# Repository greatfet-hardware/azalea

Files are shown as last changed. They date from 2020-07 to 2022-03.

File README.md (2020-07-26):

# Azalea

Hardware licensed under the BSD 3 clause license
Documentation licensed under the BSD 3 clause license

This repository contains the KiCad design for Azalea, also known as GreatFET One.  The design requires:

https://github.com/greatscottgadgets/gsg-kicad-lib

If you are using git, the preferred way to install gsg-kicad-lib is to use the submodule:

```
git submodule init && git submodule update
```

## Overview

Also known as GreatFET One, Azalea is the main board of the GreatFET project.

Azalea is a peripheral interface tool.  By adding expansion boards called "neighbors", you can turn Azalea into a USB peripheral that does almost anything.

Features:
* LPC4330 microcontroller (U1)
* Hi-Speed USB port (USB0) for connection to a host computer
* Expansion interface (J1 and J2) of 80 pins (2 female headers with 2 rows of 20 pins)
* Bonus row of 20 male pins (J7)
* 4 indicator LEDs
* 2 buttons, primarily for development (DFU and RESET, just like HackRF One)
* Full Speed USB port (USB1) for connection to a target (for [Facedancer](https://github.com/usb-tools/Facedancer))
* Power switching for use of USB1 as either host or device
* 3.3 V regulator that can supply some power to neighbors
* 2 MB flash memory
* Unpopulated Cortex Debug Header (J5) for JTAG or SWD

Except where noted below, all pins on expansion ports use 3.3 V I/O voltage.

## J1 (NEIGHBOR1) Pinout

Pin|Symbol|Special Function|Notes    |U1 Pin|GPIO |U0 |U1 |U2  |EMC        |SGPIO|ENET      |CAN1|SSP0|SSP1|I2S0           |I2S1  |USB0     |USB1     |SD   |MISC   |PWM  |TIMER  |SCT     
---|------|----------------|---------|------|-----|---|---|----|-----------|-----|----------|----|----|----|---------------|------|---------|---------|-----|-------|-----|-------|--------
1  |GND   |                |         |      |     |   |   |    |           |     |          |    |    |    |               |      |         |         |     |       |     |       |        
2  |VCC   |                |3.3 V    |      |     |   |   |    |           |     |          |    |    |    |               |      |         |         |     |       |     |       |        
3  |P4_9  |                |         |33    |5[13]|   |   |    |           |14   |          |RD  |    |    |               |      |         |         |     |       |     |       |CTIN_6  
4  |P0_0  |                |         |32    |0[0] |   |   |    |           |0    |RXD1      |    |    |CIPO|TX_WS          |TX_WS |         |         |     |       |     |       |        
5  |P4_10 |                |         |35    |5[14]|   |   |    |           |15   |          |    |    |    |               |      |         |         |     |       |     |       |CTIN_2  
6  |P0_1  |                |         |34    |0[1] |   |   |    |           |1    |TX_EN     |    |    |COPI|               |TX_SDA|         |         |     |       |     |       |        
7  |P1_0  |                |         |38    |0[4] |   |   |    |A5         |7    |          |    |CS  |    |               |      |         |         |     |       |     |       |CTIN_3  
8  |P5_0  |                |         |37    |2[9] |   |DSR|    |D12        |     |          |    |    |    |               |      |         |         |     |       |MCOB2|T1_CAP0|        
9  |P5_1  |                |         |39    |2[10]|   |DTR|    |D13        |     |          |    |    |    |               |      |         |         |     |       |MCI2 |T1_CAP1|        
10 |P1_1  |boot mode       |pull-up  |42    |0[8] |   |   |    |A6         |8    |          |    |CIPO|    |               |      |         |         |     |       |     |       |CTOUT_7 
11 |CLK0  |                |         |45    |     |   |   |    |CLK0, CLK01|     |REF_CLK   |    |    |SCK |               |      |         |         |CLK  |CLKOUT |     |       |        
12 |P1_2  |boot mode       |pull-down|43    |0[9] |   |   |    |A7         |9    |          |    |COPI|    |               |      |         |         |     |       |     |       |CTOUT_6 
13 |P1_5  |                |         |48    |1[8] |   |   |    |CS0#       |15   |          |    |    |CS  |               |      |PWR_FAULT|         |POW  |       |     |       |CTOUT_10
14 |P5_2  |                |         |46    |2[11]|   |RTS|    |D14        |     |          |    |    |    |               |      |         |         |     |       |MCI1 |T1_CAP2|        
15 |P1_7  |                |         |50    |1[0] |   |DSR|    |D0         |     |          |    |    |    |               |      |PPWR     |         |     |       |     |       |CTIN_1  
16 |P1_6  |                |         |49    |1[9] |   |   |    |WE#        |14   |          |    |    |    |               |      |         |         |CMD  |       |     |       |CTIN_5  
17 |P1_9  |                |         |52    |1[2] |   |RTS|    |D2         |     |          |    |    |    |               |      |         |         |DAT0 |       |     |       |CTOUT_11
18 |P1_8  |                |         |51    |1[1] |   |DTR|    |D1         |     |          |    |    |    |               |      |         |         |VOLT0|       |     |       |CTOUT_12
19 |P5_3  |                |         |54    |2[12]|   |RI |    |D15        |     |          |    |    |    |               |      |         |         |     |       |MCI0 |T1_CAP3|        
20 |P1_10 |                |         |53    |1[3] |   |RI |    |D3         |     |          |    |    |    |               |      |         |         |DAT1 |       |     |       |CTOUT_14
21 |P1_12 |                |         |56    |1[5] |   |DCD|    |D5         |8    |          |    |    |    |               |      |         |         |DAT3 |       |     |T0_CAP1|        
22 |P1_11 |                |         |55    |1[4] |   |CTS|    |D4         |     |          |    |    |    |               |      |         |         |DAT2 |       |     |       |CTOUT_15
23 |P5_5  |                |         |58    |2[14]|   |DCD|    |D9         |     |          |    |    |    |               |      |         |         |     |       |MCOA1|T1_MAT1|        
24 |P5_4  |                |         |57    |2[13]|   |CTS|    |D8         |     |          |    |    |    |               |      |         |         |     |       |MCOB0|T1_MAT0|        
25 |P1_14 |                |         |61    |1[7] |   |RXD|    |D7         |10   |          |    |    |    |               |      |         |         |     |       |     |T0_MAT2|        
26 |P1_13 |                |         |60    |1[6] |   |TXD|    |D6         |9    |          |    |    |    |               |      |         |         |CD   |       |     |T0_CAP0|        
27 |P5_6  |                |         |63    |2[15]|   |TXD|    |D10        |     |          |    |    |    |               |      |         |         |     |       |MCOB1|T1_MAT2|        
28 |P1_15 |                |         |62    |0[2] |   |   |TXD |           |2    |RXD0      |    |    |    |               |      |         |         |     |       |     |T0_MAT1|        
29 |P5_7  |                |         |65    |2[7] |   |RXD|    |D11        |     |          |    |    |    |               |      |         |         |     |       |     |T1_MAT3|        
30 |P1_16 |                |         |64    |0[3] |   |   |RXD |           |3    |CRS, RX_DV|    |    |    |               |      |         |         |     |       |MCOA2|T0_MAT0|        
31 |P1_18 |                |         |67    |0[13]|   |   |DIR |           |12   |TXD0      |RD  |    |    |               |      |         |         |     |       |     |T0_MAT3|        
32 |P1_17 |                |         |66    |0[12]|   |   |UCLK|           |11   |MDIO      |TD  |    |    |               |      |         |         |     |       |     |T0_CAP3|        
33 |P9_5  |                |         |69    |5[18]|TXD|   |    |           |3    |          |    |    |    |               |      |         |PPWR     |     |       |MCOA1|       |        
34 |P9_6  |                |         |72    |4[11]|RXD|   |    |           |8    |          |    |    |    |               |      |         |PWR_FAULT|     |       |MCOB1|       |        
35 |P2_0  |                |         |75    |5[0] |TXD|   |    |A13        |4    |MDC       |    |    |    |               |      |PPWR     |         |     |ISP_TXD|     |T3_CAP0|        
36 |P6_0  |                |         |73    |     |   |   |    |           |     |          |    |    |    |RX_MCLK, RX_SCK|      |         |         |     |       |     |       |        
37 |P1_20 |                |         |70    |0[15]|   |   |    |           |13   |TXD1      |    |    |CS  |               |      |         |         |     |       |     |T0_CAP2|        
38 |P1_19 |                |         |68    |     |   |   |    |           |     |REF_CLK   |    |    |SCK |RX_MCLK        |TX_SCK|         |         |     |CLKOUT |     |       |        
39 |P1_4  |                |         |47    |0[11]|   |   |    |BLS0#      |11   |          |    |    |COPI|               |      |IND0     |         |VOLT1|       |     |       |CTOUT_9 
40 |P1_3  |                |         |44    |0[10]|   |   |    |OE#        |10   |          |    |    |CIPO|               |      |IND1     |         |     |       |     |       |CTOUT_8 

## J2 (NEIGHBOR2) Pinout

Pin|Symbol  |Special Function|Notes            |U1 Pin|GPIO |U0  |U1 |U2 |U3  |EMC        |SGPIO|RMII|CAN0|CAN1|SPI |SSP0      |SSP1|SPIFI|I2S0                            |I2S1  |I2C0|I2C1|USB0     |USB1|SD |ADC     |MISC              |PWM  |TIMER  |SCT     
---|--------|----------------|-----------------|------|-----|----|---|---|----|-----------|-----|----|----|----|----|----------|----|-----|--------------------------------|------|----|----|---------|----|---|--------|------------------|-----|-------|--------
1  |GND     |                |                 |      |     |    |   |   |    |           |     |    |    |    |    |          |    |     |                                |      |    |    |         |    |   |        |                  |     |       |        
2  |5V      |                |                 |      |     |    |   |   |    |           |     |    |    |    |    |          |    |     |                                |      |    |    |         |    |   |        |                  |     |       |        
3  |P4_8    |                |                 |15    |5[12]|    |   |   |    |           |13   |    |    |TD  |    |          |    |     |                                |      |    |    |         |    |   |        |                  |     |       |CTIN_5  
4  |P4_0    |                |                 |1     |2[0] |    |   |   |UCLK|           |     |    |    |    |    |          |    |     |                                |      |    |    |         |    |   |        |NMI               |MCOA0|       |        
5  |ADC0_0  |                |                 |6     |     |    |   |   |    |           |     |    |    |    |    |          |    |     |                                |      |    |    |         |    |   |0_0, 1_0|DAC               |     |       |        
6  |P4_5    |                |                 |10    |2[5] |    |   |   |    |           |11   |    |    |    |    |          |    |     |                                |      |    |    |         |    |   |        |                  |     |       |CTOUT_5 
7  |P4_4    |                |                 |9     |2[4] |    |   |   |DIR |           |10   |    |    |    |    |          |    |     |                                |      |    |    |         |    |   |        |DAC               |     |       |CTOUT_2 
8  |P4_2    |                |                 |8     |2[2] |    |   |   |RXD |           |8    |    |    |    |    |          |    |     |                                |      |    |    |         |    |   |        |                  |     |       |CTOUT_0 
9  |P4_3    |                |                 |7     |2[3] |    |   |   |BAUD|           |9    |    |    |    |    |          |    |     |                                |      |    |    |         |    |   |0_0     |                  |     |       |CTOUT_3 
10 |P4_6    |                |                 |11    |2[6] |    |   |   |    |           |12   |    |    |    |    |          |    |     |                                |      |    |    |         |    |   |        |                  |     |       |CTOUT_4 
11 |P4_7    |                |                 |14    |     |    |   |   |    |           |     |    |    |    |    |          |    |     |TX_SCK                          |TX_SCK|    |    |         |    |   |        |GP_CLKIN          |     |       |        
12 |CLK2    |                |                 |99    |     |    |   |   |    |CLK3, CLK23|     |    |    |    |    |          |    |     |TX_MCLK                         |RX_SCK|    |    |         |    |CLK|        |CLKOUT            |     |       |        
13 |P2_8    |DFU, boot mode  |pull-down, button|98    |5[7] |    |   |   |DIR |A8         |15   |    |    |    |    |          |    |     |                                |      |    |    |         |    |   |        |                  |     |       |CTOUT_0 
14 |P2_7    |ISP, boot mode  |pull-up          |96    |0[7] |    |   |   |UCLK|A9         |     |    |    |    |    |          |    |     |                                |      |    |    |         |    |   |        |                  |     |T3_MAT3|CTOUT_1 
15 |P2_6    |                |                 |95    |5[6] |DIR |   |   |    |A10        |7    |    |    |    |    |          |    |     |                                |      |    |    |IND0     |    |   |        |                  |     |T3_CAP3|CTIN_7  
16 |P7_7    |                |                 |140   |3[15]|    |   |   |    |           |7    |MDC |    |    |    |          |    |     |                                |      |    |    |         |    |   |1_6     |TRACEDATA[3]      |     |       |CTOUT_8 
17 |WAKEUP0 |                |pull-up          |130   |     |    |   |   |    |           |     |    |    |    |    |          |    |     |                                |      |    |    |         |    |   |        |WAKEUP0           |     |       |        
18 |P2_5    |                |                 |91    |5[5] |    |   |   |    |           |14   |    |    |    |    |          |    |     |                                |      |    |    |IND0     |VBUS|   |TRIG1   |                  |     |T3_MAT2|CTIN_2  
19 |P2_4    |                |                 |88    |5[4] |    |   |   |RXD |           |13   |    |    |    |    |          |    |     |                                |      |    |SCL |PWR_FAULT|    |   |        |                  |     |T3_MAT1|CTIN_0  
20 |P2_3    |                |                 |87    |5[3] |    |   |   |TXD |           |12   |    |    |    |    |          |    |     |                                |      |    |SDA |PPWR     |    |   |        |                  |     |T3_MAT0|CTIN_1  
21 |PF_4    |                |                 |120   |     |    |   |   |    |           |     |    |    |    |    |          |SCK |     |TX_MCLK, RX_SCK                 |      |    |    |         |    |   |        |GP_CLKIN, TRACECLK|     |       |        
22 |P3_2    |                |                 |116   |5[9] |    |   |   |    |           |     |    |TD  |    |    |          |    |     |TX_SDA, RX_SDA                  |      |    |    |         |IND0|   |        |                  |     |       |        
23 |P7_2    |                |                 |115   |3[10]|    |   |RXD|    |           |6    |    |    |    |    |          |    |     |TX_SDA                          |      |    |    |         |    |   |        |                  |     |       |CTIN_4  
24 |P3_1    |                |                 |114   |5[8] |    |   |   |    |           |     |    |RD  |    |    |          |    |     |TX_WS, RX_WS                    |      |    |    |         |IND1|   |        |                  |     |       |        
25 |P7_1    |                |                 |113   |3[9] |    |   |TXD|    |           |5    |    |    |    |    |          |    |     |TX_WS                           |      |    |    |         |    |   |        |                  |     |       |CTOUT_15
26 |P3_0    |                |                 |112   |     |    |   |   |    |           |     |    |    |    |    |SCK       |    |     |RX_SCK, RX_MCLK, TX_SCK, TX_MCLK|      |    |    |         |    |   |        |                  |     |       |        
27 |P7_0    |                |                 |110   |3[8] |    |   |   |    |           |4    |    |    |    |    |          |    |     |                                |      |    |    |         |    |   |        |                  |     |       |CTOUT_14
28 |P3_4    |                |                 |119   |1[14]|    |TXD|   |    |           |     |    |    |    |    |          |    |SIO3 |TX_WS                           |RX_SDA|    |    |         |    |   |        |                  |     |       |        
29 |P6_8    |                |                 |86    |5[16]|    |   |   |    |A14        |7    |    |    |    |    |          |    |     |                                |      |    |    |IND0     |    |   |        |                  |     |T2_MAT1|        
30 |P3_7    |                |                 |123   |5[10]|    |   |   |    |           |     |    |    |    |COPI|CIPO, COPI|    |COPI |                                |      |    |    |         |    |   |        |                  |     |       |        
31 |P6_7    |                |                 |85    |5[15]|    |   |   |    |A15        |6    |    |    |    |    |          |    |     |                                |      |    |    |IND1     |    |   |        |                  |     |T2_MAT0|        
32 |P3_3    |                |                 |118   |     |    |   |   |    |           |     |    |    |    |SCK |SCK       |    |SCK  |TX_MCLK                         |TX_SCK|    |    |         |    |   |        |CGU_OUT1          |     |       |        
33 |P2_2    |                |                 |84    |5[2] |UCLK|   |   |    |A11        |6    |    |    |    |    |          |    |     |                                |      |    |    |IND1     |    |   |        |                  |     |T3_CAP2|CTIN_6  
34 |P6_6    |                |                 |83    |0[5] |    |   |   |    |BLS1#      |5    |    |    |    |    |          |    |     |                                |      |    |    |PWR_FAULT|    |   |        |                  |     |T2_CAP3|        
35 |P2_1    | neighbor WC    |                 |81    |5[1] |RXD |   |   |    |A12        |5    |    |    |    |    |          |    |     |                                |      |    |    |PWR_FAULT|    |   |        |ISP_RXD           |     |T3_CAP1|        
36 |P6_3    |                |                 |79    |3[2] |    |   |   |    |CS1#       |4    |    |    |    |    |          |    |     |                                |      |    |    |PPWR     |    |   |        |                  |     |T2_CAP2|        
37 |P3_5    |                |                 |121   |1[15]|    |RXD|   |    |           |     |    |    |    |    |          |    |SIO2 |TX_SDA                          |RX_WS |    |    |         |    |   |        |                  |     |       |        
38 |P3_6    |                |                 |122   |0[6] |    |   |   |    |           |     |    |    |    |CIPO|CS,   CIPO|    |CIPO |                                |      |    |    |         |    |   |        |                  |     |       |        
39 |I2C0_SDA|                |pull-up          |93    |     |    |   |   |    |           |     |    |    |    |    |          |    |     |                                |      |SDA |    |         |    |   |        |                  |     |       |        
40 |I2C0_SCL|                |pull-up          |92    |     |    |   |   |    |           |     |    |    |    |    |          |    |     |                                |      |SCL |    |         |    |   |        |                  |     |       |        

## J5 (JTAG) Pinout

Pin|Symbol    |Notes          |U1 Pin
---|----------|---------------|------
1  |VCC       |3.3 V          |      
2  |TMS/SWDIO |               |30    
3  |GND       |               |      
4  |TCK/SWDCLK|pull-up        |27    
5  |GND       |               |      
6  |TDO/SWO   |pull-up        |31    
7  |          |not connected  |      
8  |TDI       |               |26    
9  |GND       |               |      
10 |RESET#    |pull-up, button|128   

## J7 (BONUS_ROW) Pinout

Pin|Symbol       |Special Function|Notes          |U1 Pin|GPIO |U0  |U2  |U3  |EMC    |I2S0  |ADC     |PWM    |TIMER  |SCT    
---|-------------|----------------|---------------|------|-----|----|----|----|-------|------|--------|-------|-------|-------
1  |GND          |                |               |      |     |    |    |    |       |      |        |       |       |       
2  |P6_4         |                |               |80    |3[3] |TXD |    |    |CAS#   |      |        |       |       |CTIN_6 
3  |P6_5         |                |               |82    |3[4] |RXD |    |    |RAS#   |      |        |       |       |CTOUT_6
4  |ADC0_5/ADC1_5|                |               |144   |     |    |    |    |       |      |0_5, 1_5|       |       |       
5  |ADC0_2/ADC1_2|                |               |143   |     |    |    |    |       |      |0_2, 1_2|       |       |       
6  |P2_9         |boot mode       |pull-down      |102   |1[10]|    |    |BAUD|A0     |      |        |       |       |CTOUT_3
7  |P2_12        |                |               |106   |1[12]|    |UCLK|    |A3     |      |        |       |       |CTOUT_4
8  |P2_13        |                |               |108   |1[13]|    |DIR |    |A4     |      |        |       |       |CTIN_4 
9  |RTC_ALARM    |                |               |129   |     |    |    |    |       |      |        |       |       |       
10 |RTCX1        |                |               |      |     |    |    |    |       |      |        |       |       |       
11 |RESET#       |                |pull-up, button|128   |     |    |    |    |       |      |        |       |       |       
12 |VBAT         |                |               |127   |     |    |    |    |       |      |        |       |       |       
13 |P2_11        |                |               |105   |1[11]|    |RXD |    |A2     |      |        |       |       |CTOUT_5
14 |P2_10        |                |               |104   |0[14]|    |TXD |    |A1     |      |        |       |       |CTOUT_2
15 |P6_10        |                |               |100   |3[6] |    |    |    |DQMOUT1|      |        |MCABORT|       |       
16 |P6_9         |                |               |97    |3[5] |    |    |    |DYCS0# |      |        |       |T2_MAT2|       
17 |P6_2         |                |               |78    |3[1] |DIR |    |    |CKEOUT1|RX_SDA|        |       |T2_CAP1|       
18 |P6_1         |                |               |74    |3[0] |UCLK|    |    |DYCS1# |RX_WS |        |       |T2_CAP0|       
19 |GND          |                |               |      |     |    |    |    |       |      |        |       |       |       
20 |VCC          |                |3.3 V          |      |     |    |    |    |       |      |        |       |       |       

## Clear Acrylic Case

Hardware licensed under the BSD 3 clause license
Documentation licensed under the BSD 3 clause license

The vector graphic file provided in this repo was created with Inkscape.

The black lines are the edge cuts. The blue lines are cut outs. The red lines are optional and should be lightly etched if they are used.
The red lines are meant to be used to help count holes in the headers.

### The BOM 

* 4 x 4.5 mm OD Hex Standoffs (Female-Female) / M3-0.5 x 6 mm / Aluminum
* 4 x 4.5 mm OD Hex Standoffs (Female-Female) / M3-0.5 x 5 mm / Aluminum
* 4 x M3-0.5 x 12 mm / Phillips Pan Head Machine Screw
* 4 x M3-0.5 x 5 mm / Phillips Pan Head Machine Screw

Optional:
* 4 (per neighbor) x 4.5 mm OD Hex Standoffs (Male-Female) / M3-0.5 x 11 mm / Aluminum

These standoffs are to be used if a neighbor is stacked on your GreatFET One and you want your case to be stacked above that neighbor.

### Assembly Instructions 

Assembly instructions can be found [here.](https://www.greatscottgadgets.com/greatfet/acrylic-case/)

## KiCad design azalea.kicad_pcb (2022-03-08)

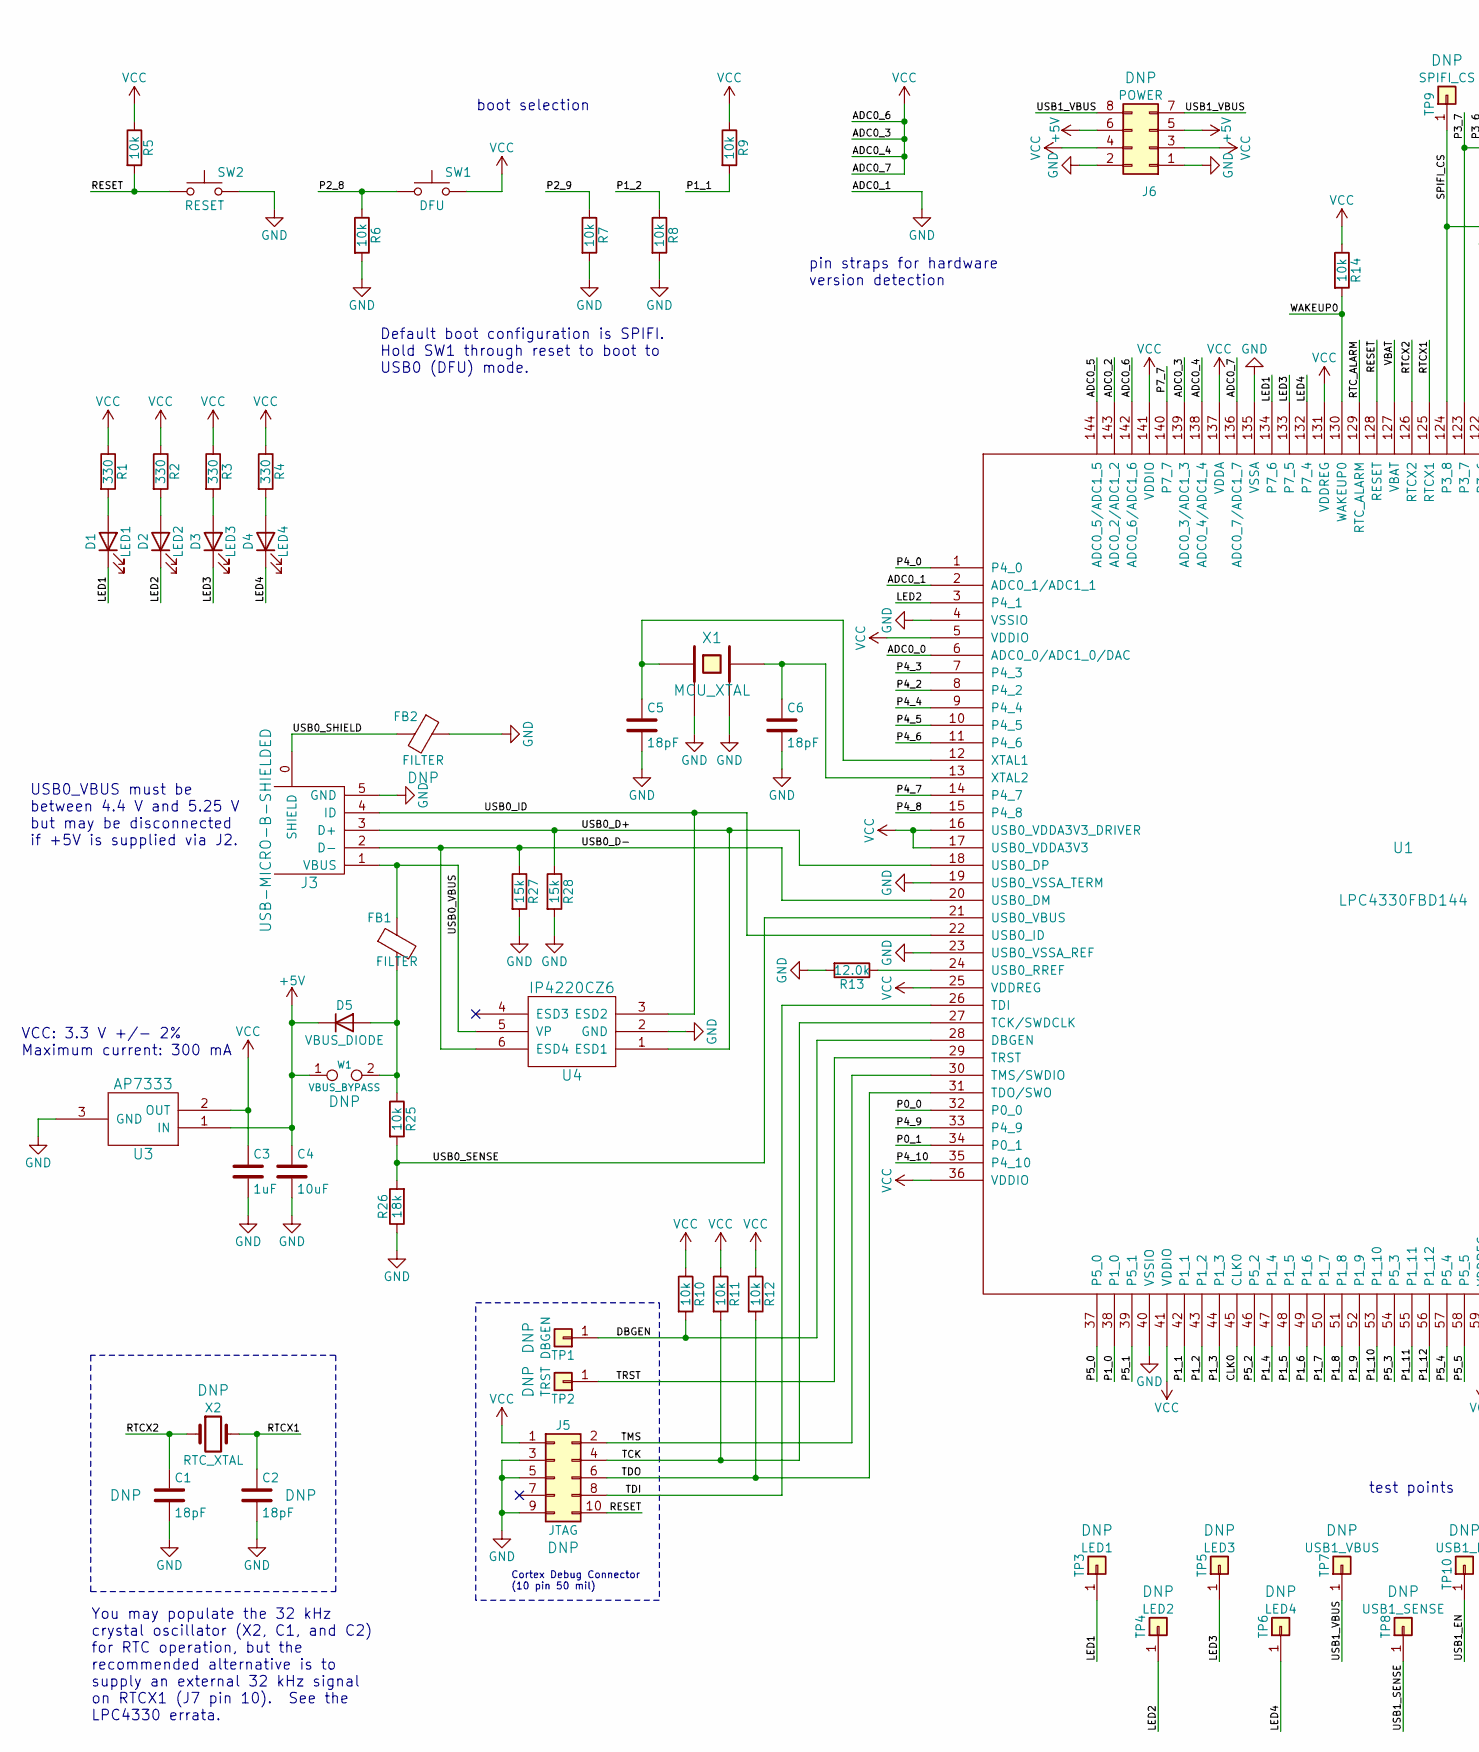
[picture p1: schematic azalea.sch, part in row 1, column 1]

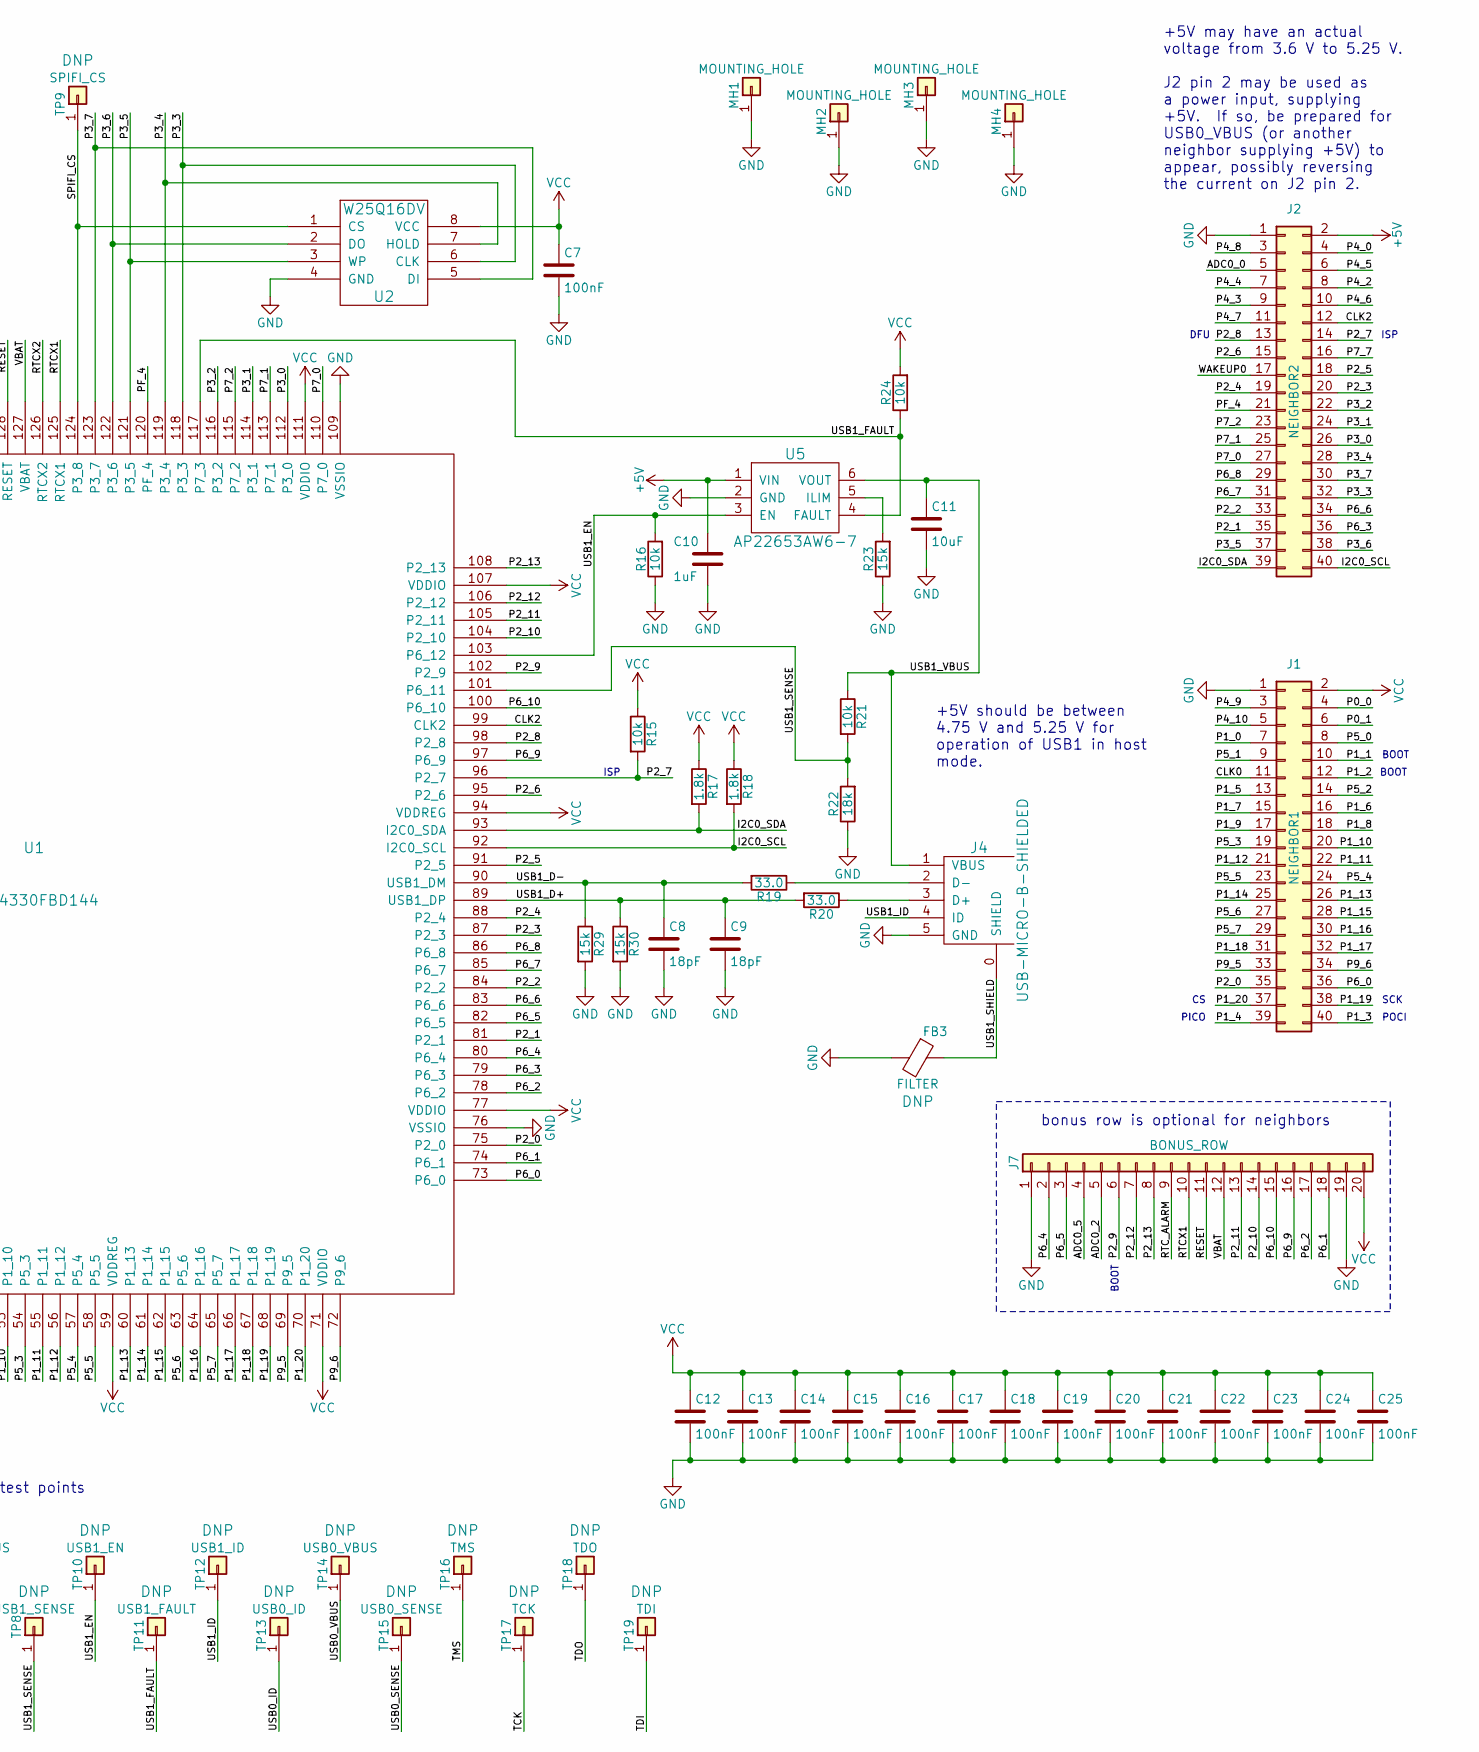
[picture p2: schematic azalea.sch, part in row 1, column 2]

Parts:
C1, C2, C5, C6, C8, C9: 18pF; 0603; Part Number C0603C180J5GAC
C3, C10: 1uF; 0603; Part Number LMK107B7105KA-T
C4, C11: 10uF; 0805; Part Number LMK212ABJ106KG-T
C7, C12, C13, C14, C15, C16, C17, C18, C19, C20, C21, C22, C23, C24, C25: 100nF; 0603; Part Number C0603C104M4RAC
D1: LED1; 0603D; Part Number SML-LX0603GW-TR
D2: LED2; 0603D; Part Number SML-LX0603YW-TR
D3: LED3; 0603D; Part Number SML-LX0603GW-TR
D4: LED4; 0603D; Part Number SML-LX0603YW-TR
D5: VBUS_DIODE; SOD128; Part Number PMEG3050EP,115
FB1, FB2, FB3: FILTER; 0805; Part Number BLM21PG221SN1D
J1: NEIGHBOR1; HEADER-2x20; Part Number SSW-120-01-F-D
J2: NEIGHBOR2; HEADER-2x20; Part Number SSW-120-01-F-D
J3, J4: USB-MICRO-B-SHIELDED; USB-MICROB-FCI-10103592-LONGPADS; Part Number 10103592-0001LF
J5: JTAG; 50MIL-HEADER-2x5-TH
J6: POWER; HEADER-SMT-2x4
J7: BONUS_ROW; HEADER-1x20; Part Number PRPC020SAAN-RC
MH1, MH2, MH3, MH4: MOUNTING_HOLE; HOLE126MIL-COPPER
R1, R2, R3, R4: 330; 0603; Part Number RMCF0603JT330R
R5, R6, R7, R8, R9, R10, R11, R12, R14, R15, R16, R21, R24, R25: 10k; 0603; Part Number ERJ-3GEYJ103V
R13: 12.0k; 0603; Part Number RMCF0603FT12K0
R17, R18: 1.8k; 0603; Part Number RMCF0603JT1K80
R19, R20: 33.0; 0603; Part Number RC0603FR-0733RL
R22, R26: 18k; 0603; Part Number RC0603JR-0718KL
R23, R27, R28, R29, R30: 15k; 0603; Part Number RC0603JR-0715KL
SW1: DFU; SWITCH-PTS840-P; Part Number PTS840 PM SMTR LFS
SW2: RESET; SWITCH-PTS840-P; Part Number PTS840 PM SMTR LFS
TP1: DBGEN; TESTPOINT-50MIL
TP2: TRST; TESTPOINT-50MIL
TP3: LED1; TESTPOINT-50MIL
TP4: LED2; TESTPOINT-50MIL
TP5: LED3; TESTPOINT-50MIL
TP6: LED4; TESTPOINT-50MIL
TP7: USB1_VBUS; TESTPOINT-50MIL
TP8: USB1_SENSE; TESTPOINT-50MIL
TP9: SPIFI_CS; TESTPOINT-50MIL
TP10: USB1_EN; TESTPOINT-50MIL
TP11: USB1_FAULT; TESTPOINT-50MIL
TP12: USB1_ID; TESTPOINT-50MIL
TP13: USB0_ID; TESTPOINT-50MIL
TP14: USB0_VBUS; TESTPOINT-50MIL
TP15: USB0_SENSE; TESTPOINT-50MIL
TP16: TMS; TESTPOINT-50MIL
TP17: TCK; TESTPOINT-50MIL
TP18: TDO; TESTPOINT-50MIL
TP19: TDI; TESTPOINT-50MIL
U1: LPC4330FBD144; LQFP144; Part Number LPC4330FBD144,551
U2: W25Q16DV; SOIC8-208; Part Number W25Q16JVSSIQ
U3: AP7333; SOT23-3; Part Number AP7333-33SAG-7
U4: IP4220CZ6; SOT457; Part Number IP4220CZ6,125
U5: AP22653AW6-7; SOT457; Part Number AP22653AW6-7
W1: VBUS_BYPASS; 0603-JUMPER
X1: MCU_XTAL; XTAL3.2x2.5mm-EXT; Part Number 7V-12.000MAAE-T
X2: RTC_XTAL; XTAL-AB26TRQ; Part Number AB26TRQ-32.768KHZ-T

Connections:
+5V: C4.1, C10.1, D5.1 (K), J2.2, J6.5, J6.6, U3.1 (IN), U5.1 (VIN), W1.1
/ADC0_0: J2.5, U1.6 (ADC0_0/ADC1_0/DAC)
/ADC0_2: J7.5, U1.143 (ADC0_2/ADC1_2)
/ADC0_5: J7.4, U1.144 (ADC0_5/ADC1_5)
/CLK0: J1.11, U1.45 (CLK0)
/CLK2: J2.12, U1.99 (CLK2)
/DBGEN: R10.2, TP1.1, U1.28 (DBGEN)
/I2C0_SCL: J2.40, R18.2, U1.92 (I2C0_SCL)
/I2C0_SDA: J2.39, R17.2, U1.93 (I2C0_SDA)
/LED1: D1.1 (K), TP3.1, U1.134 (P7_6)
/LED2: D2.1 (K), TP4.1, U1.3 (P4_1)
/LED3: D3.1 (K), TP5.1, U1.133 (P7_5)
/LED4: D4.1 (K), TP6.1, U1.132 (P7_4)
/P0_0: J1.4, U1.32 (P0_0)
/P0_1: J1.6, U1.34 (P0_1)
/P1_0: J1.7, U1.38 (P1_0)
/P1_1: J1.10, R9.2, U1.42 (P1_1)
/P1_2: J1.12, R8.1, U1.43 (P1_2)
/P1_3: J1.40, U1.44 (P1_3)
/P1_4: J1.39, U1.47 (P1_4)
/P1_5: J1.13, U1.48 (P1_5)
/P1_6: J1.16, U1.49 (P1_6)
/P1_7: J1.15, U1.50 (P1_7)
/P1_8: J1.18, U1.51 (P1_8)
/P1_9: J1.17, U1.52 (P1_9)
/P1_10: J1.20, U1.53 (P1_10)
/P1_11: J1.22, U1.55 (P1_11)
/P1_12: J1.21, U1.56 (P1_12)
/P1_13: J1.26, U1.60 (P1_13)
/P1_14: J1.25, U1.61 (P1_14)
/P1_15: J1.28, U1.62 (P1_15)
/P1_16: J1.30, U1.64 (P1_16)
/P1_17: J1.32, U1.66 (P1_17)
/P1_18: J1.31, U1.67 (P1_18)
/P1_19: J1.38, U1.68 (P1_19)
/P1_20: J1.37, U1.70 (P1_20)
/P2_0: J1.35, U1.75 (P2_0)
/P2_1: J2.35, U1.81 (P2_1)
/P2_2: J2.33, U1.84 (P2_2)
/P2_3: J2.20, U1.87 (P2_3)
/P2_4: J2.19, U1.88 (P2_4)
/P2_5: J2.18, U1.91 (P2_5)
/P2_6: J2.15, U1.95 (P2_6)
/P2_7: J2.14, R15.2, U1.96 (P2_7)
/P2_8: J2.13, R6.1, SW1.1, U1.98 (P2_8)
/P2_9: J7.6, R7.1, U1.102 (P2_9)
/P2_10: J7.14, U1.104 (P2_10)
/P2_11: J7.13, U1.105 (P2_11)
/P2_12: J7.7, U1.106 (P2_12)
/P2_13: J7.8, U1.108 (P2_13)
/P3_0: J2.26, U1.112 (P3_0)
/P3_1: J2.24, U1.114 (P3_1)
/P3_2: J2.22, U1.116 (P3_2)
/P3_3: J2.32, U1.118 (P3_3), U2.6 (CLK)
/P3_4: J2.28, U1.119 (P3_4), U2.7 (HOLD)
/P3_5: J2.37, U1.121 (P3_5), U2.3 (WP)
/P3_6: J2.38, U1.122 (P3_6), U2.2 (DO)
/P3_7: J2.30, U1.123 (P3_7), U2.5 (DI)
/P4_0: J2.4, U1.1 (P4_0)
/P4_2: J2.8, U1.8 (P4_2)
/P4_3: J2.9, U1.7 (P4_3)
/P4_4: J2.7, U1.9 (P4_4)
/P4_5: J2.6, U1.10 (P4_5)
/P4_6: J2.10, U1.11 (P4_6)
/P4_7: J2.11, U1.14 (P4_7)
/P4_8: J2.3, U1.15 (P4_8)
/P4_9: J1.3, U1.33 (P4_9)
/P4_10: J1.5, U1.35 (P4_10)
/P5_0: J1.8, U1.37 (P5_0)
/P5_1: J1.9, U1.39 (P5_1)
/P5_2: J1.14, U1.46 (P5_2)
/P5_3: J1.19, U1.54 (P5_3)
/P5_4: J1.24, U1.57 (P5_4)
/P5_5: J1.23, U1.58 (P5_5)
/P5_6: J1.27, U1.63 (P5_6)
/P5_7: J1.29, U1.65 (P5_7)
/P6_0: J1.36, U1.73 (P6_0)
/P6_1: J7.18, U1.74 (P6_1)
/P6_2: J7.17, U1.78 (P6_2)
/P6_3: J2.36, U1.79 (P6_3)
/P6_4: J7.2, U1.80 (P6_4)
/P6_5: J7.3, U1.82 (P6_5)
/P6_6: J2.34, U1.83 (P6_6)
/P6_7: J2.31, U1.85 (P6_7)
/P6_8: J2.29, U1.86 (P6_8)
/P6_9: J7.16, U1.97 (P6_9)
/P6_10: J7.15, U1.100 (P6_10)
/P7_0: J2.27, U1.110 (P7_0)
/P7_1: J2.25, U1.113 (P7_1)
/P7_2: J2.23, U1.115 (P7_2)
/P7_7: J2.16, U1.140 (P7_7)
/P9_5: J1.33, U1.69 (P9_5)
/P9_6: J1.34, U1.72 (P9_6)
/PF_4: J2.21, U1.120 (PF_4)
/RESET: J5.10, J7.11, R5.2, SW2.1, U1.128 (RESET)
/RTCX1: C2.1, J7.10, U1.125 (RTCX1), X2.2
/RTCX2: C1.1, U1.126 (RTCX2), X2.1
/RTC_ALARM: J7.9, U1.129 (RTC_ALARM)
/SPIFI_CS: TP9.1, U1.124 (P3_8), U2.1 (CS)
/TCK: J5.4, R11.2, TP17.1, U1.27 (TCK/SWDCLK)
/TDI: J5.8, TP19.1, U1.26 (TDI)
/TDO: J5.6, R12.2, TP18.1, U1.31 (TDO/SWO)
/TMS: J5.2, TP16.1, U1.30 (TMS/SWDIO)
/TRST: TP2.1, U1.29 (TRST)
/USB0_D+: J3.3 (D+), R28.1, U1.18 (USB0_DP), U4.1 (ESD1)
/USB0_D-: J3.2 (D-), R27.1, U1.20 (USB0_DM), U4.6 (ESD4)
/USB0_ID: J3.4 (ID), TP13.1, U1.22 (USB0_ID), U4.3 (ESD2)
/USB0_SENSE: R25.2, R26.2, TP15.1, U1.21 (USB0_VBUS)
/USB0_SHIELD: FB2.2, J3.0 (SHIELD)
/USB0_VBUS: FB1.1, J3.1 (VBUS), TP14.1, U4.5 (VP)
/USB1_D+: C9.1, R20.2, R30.1, U1.89 (USB1_DP)
/USB1_D-: C8.1, R19.2, R29.1, U1.90 (USB1_DM)
/USB1_EN: R16.2, TP10.1, U1.103 (P6_12), U5.3 (EN)
/USB1_FAULT: R24.1, TP11.1, U1.117 (P7_3), U5.4 (FAULT)
/USB1_ID: J4.4 (ID), TP12.1
/USB1_SENSE: R21.2, R22.2, TP8.1, U1.101 (P6_11)
/USB1_SHIELD: FB3.1, J4.0 (SHIELD)
/USB1_VBUS: C11.1, J4.1 (VBUS), J6.7, J6.8, R21.1, TP7.1, U5.6 (VOUT)
/VBAT: J7.12, U1.127 (VBAT)
/WAKEUP0: J2.17, R14.2, U1.130 (WAKEUP0)
GND: C1.2, C2.2, C3.2, C4.2, C5.2, C6.2, C7.2, C8.2, C9.2, C10.2, C11.2, C12.2, C13.2, C14.2, C15.2, C16.2, C17.2, C18.2, C19.2, C20.2, C21.2, C22.2, C23.2, C24.2, C25.2, FB2.1, FB3.2, J1.1, J2.1, J3.5 (GND), J4.5 (GND), J5.3, J5.5, J5.9, J6.1, J6.2, J7.1, J7.19, MH1.1, MH2.1, MH3.1, MH4.1, R6.2, R7.2, R8.2, R13.2, R16.1, R22.1, R23.1, R26.1, R27.2, R28.2, R29.2, R30.2, SW2.2, U1.2 (ADC0_1/ADC1_1), U1.4 (VSSIO), U1.19 (USB0_VSSA_TERM), U1.23 (USB0_VSSA_REF), U1.40 (VSSIO), U1.76 (VSSIO), U1.109 (VSSIO), U1.135 (VSSA), U2.4 (GND), U3.3 (GND), U4.2 (GND), U5.2 (GND), X1.2, X1.4
unnamed: C5.1, U1.12 (XTAL1), X1.1
unnamed: C6.1, U1.13 (XTAL2), X1.3
unnamed: D1.2 (A), R1.2
unnamed: D2.2 (A), R2.2
unnamed: D3.2 (A), R3.2
unnamed: D4.2 (A), R4.2
unnamed: D5.2 (A), FB1.2, R25.1, W1.2
unnamed: J4.2 (D-), R19.1
unnamed: J4.3 (D+), R20.1
unnamed: R13.1, U1.24 (USB0_RREF)
unnamed: R23.2, U5.5 (ILIM)
VCC: C3.1, C7.1, C12.1, C13.1, C14.1, C15.1, C16.1, C17.1, C18.1, C19.1, C20.1, C21.1, C22.1, C23.1, C24.1, C25.1, J1.2, J5.1, J6.3, J6.4, J7.20, R1.1, R2.1, R3.1, R4.1, R5.1, R9.1, R10.1, R11.1, R12.1, R14.1, R15.1, R17.1, R18.1, R24.2, SW1.2, U1.5 (VDDIO), U1.16 (USB0_VDDA3V3_DRIVER), U1.17 (USB0_VDDA3V3), U1.25 (VDDREG), U1.36 (VDDIO), U1.41 (VDDIO), U1.59 (VDDREG), U1.71 (VDDIO), U1.77 (VDDIO), U1.94 (VDDREG), U1.107 (VDDIO), U1.111 (VDDIO), U1.131 (VDDREG), U1.136 (ADC0_7/ADC1_7), U1.137 (VDDA), U1.138 (ADC0_4/ADC1_4), U1.139 (ADC0_3/ADC1_3), U1.141 (VDDIO), U1.142 (ADC0_6/ADC1_6), U2.8 (VCC), U3.2 (OUT)

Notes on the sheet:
POCI
PICO
SCK
ISP
DFU
BOOT
bonus row is optional for neighbors
boot selection
test points
Default boot configuration is SPIFI. Hold SW1 through reset to boot to USB0 (DFU) mode.
Cortex Debug Connector (10 pin 50 mil)
VCC: 3.3 V +/- 2% Maximum current: 300 mA
USB0_VBUS must be between 4.4 V and 5.25 V but may be disconnected if +5V is supplied via J2.
+5V may have an actual voltage from 3.6 V to 5.25 V. J2 pin 2 may be used as a power input, supplying +5V. If so, be prepared for USB0_VBUS (or another neighbor supplying +5V) to appear, possibly reversing the current on J2 pin 2.
+5V should be between 4.75 V and 5.25 V for operation of USB1 in host mode.
pin straps for hardware version detection
You may populate the 32 kHz crystal oscillator (X2, C1, and C2) for RTC operation, but the recommended alternative is to supply an external 32 kHz signal on RTCX1 (J7 pin 10). See the LPC4330 errata.

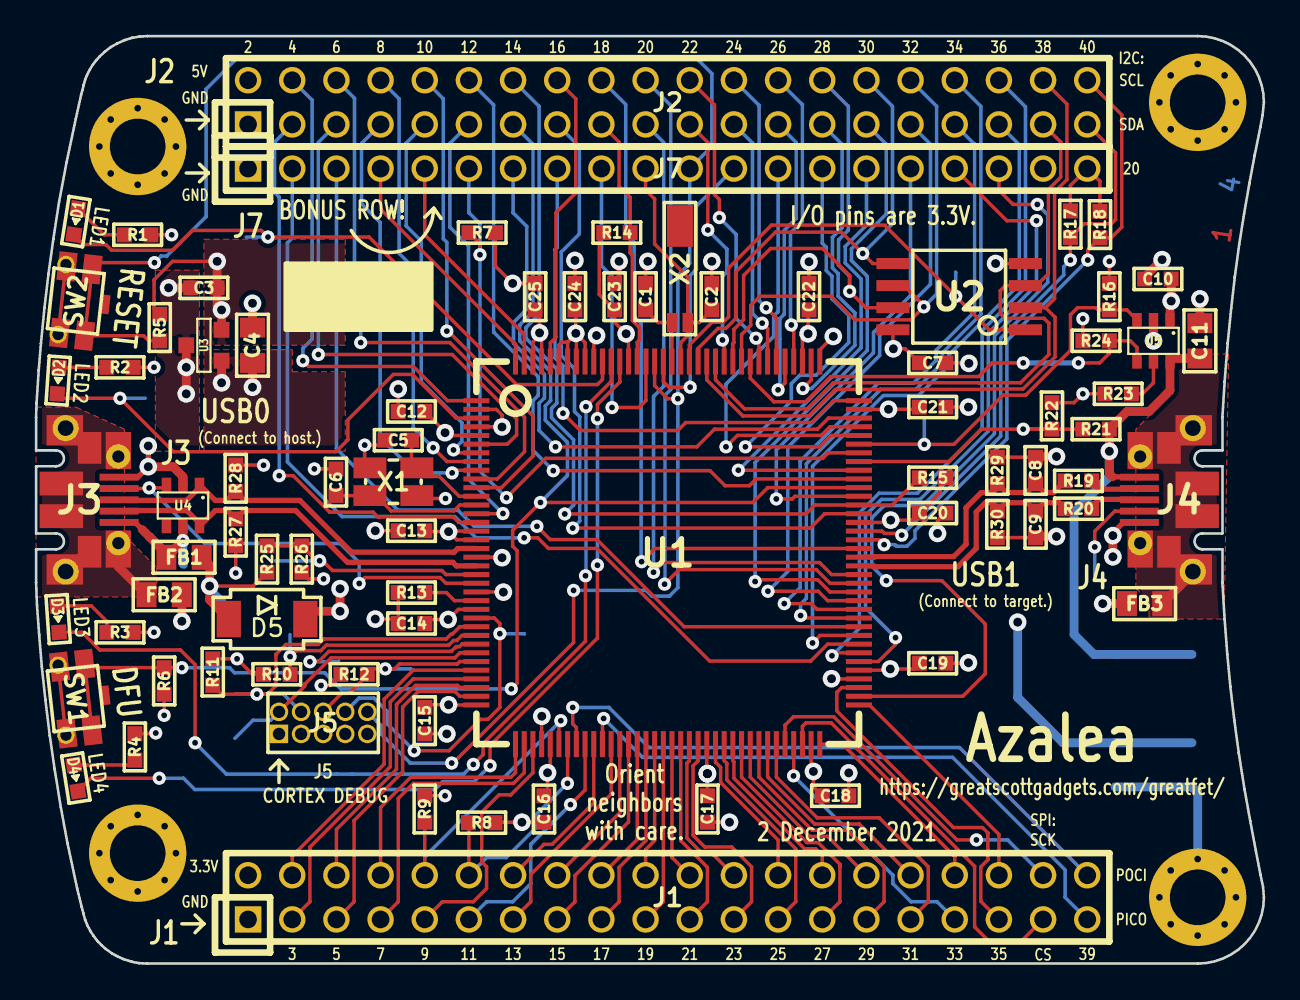
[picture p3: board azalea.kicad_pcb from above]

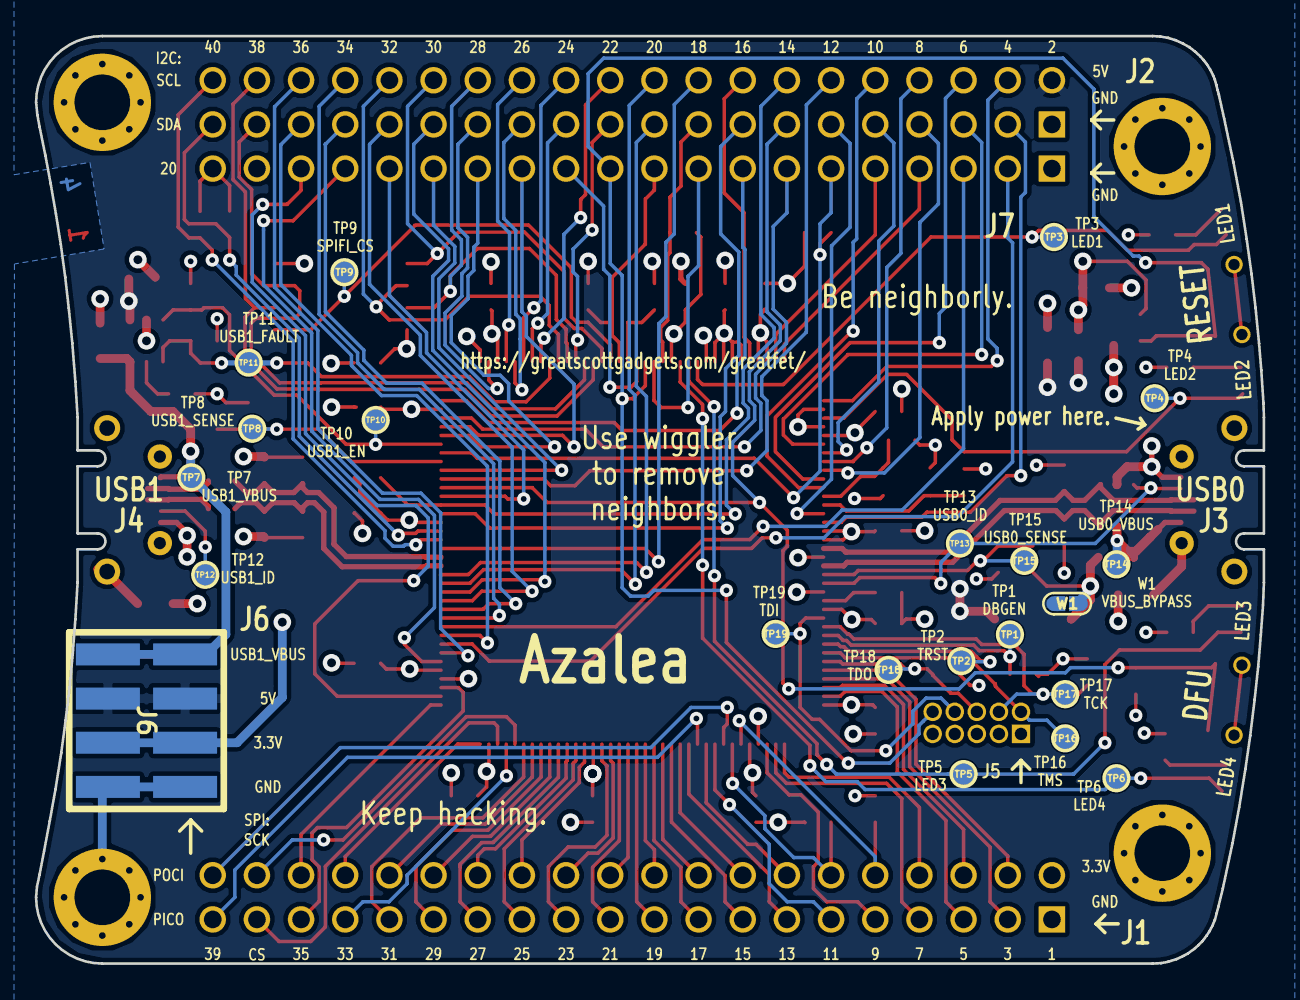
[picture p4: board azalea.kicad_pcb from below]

Board: 4 copper layers, 70.6 x 53.3 mm, 103 parts (21 on the bottom side), 133 nets.

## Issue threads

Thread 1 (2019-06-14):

Intended cable for facedancer capability

chadrockey, 2019-06-14:
I just received my unit today and noticed that it was micro usb and not USB type c (I didn't loo closely) for both connectors.

I was planning on using my GreatFet one as a Facedancer interface, but the included cable is a typical micro usb cable.

Longer term, it would be nice to use type-c for at least the target connection since those cables are reversible (host/target, not cable orientation) by design.

Medium term, it would be nice to include the intended micro-usb to target (female A?) cable.  I think we all have enough typical micro-usb around.

Short term, what cable is intended for my use of the greatfet one as a fancedancer?  A typical USB OTG Host cable?  Any suggested links or known good host cables?

mossmann, 2019-06-18:
The most common cabling for Facedancer is to use a micro cable (such as the one that ships with GreatFET One) to connect USB0 to your host computer and another micro cable to connect USB1 to a target computer.  We don't include a second cable because, as you pointed out, most folks have plenty already, and because we expect that some GreatFET users will never use USB1.

If you want to connect USB1 to a target device instead of a target host, you can use an OTG cable or adapter. This is a less common configuration because people typically use ports on their host computer (e.g. with PyUSB) for experimenting with target USB devices.

If there is a successor to Azalea it will probably have two Type-C connectors.

Closed 2019-06-18.

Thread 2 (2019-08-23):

Clarification on FB1,FB2,FB3,C1,C2,X1,X2 and D5 components

hsand, 2019-08-23:
I'm planning to build my own GreatFET One, and noticed a few components that haven't been completely documented. Based on photos of the production board C1,C2, and X2, the RTC, are unpopulated. Is there any benefit to populating the RTC, or can I just leave it off all together.

The ferrite beads FB1/2/3 don't seem to have a value assigned to them other than "FILTER". Is there a recommended value? Also FB2/3 don't appear to be populated either, not exactly sure what's best to do here.

And the MCU crystal - X1 and D5 don't have values.

Attached below is an image of production board for reference. Obtained from [https://hackaday.com/wp-content/uploads/2019/06/GreatFET-front-square.jpg](url)

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

Thanks!

Closed 2019-08-24.

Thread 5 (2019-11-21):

LPC4330 has a higher temperature

zhaohuansi, 2019-11-21:
After running IPython, the LED flashing can be controlled normally, but the LPC4330 is severely hot.Estimated temperature is 50 ° C Is this a common phenomenon? Or how many degrees Celsius is normal?

zhaohuansi, 2019-11-25:
I measured it with an infrared thermometer.  The temperature is about 40 °C, sorry.

Closed 2019-11-25.

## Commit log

2019-05-27 split azalea into separate repository
    [azalea.kicad_pcb, azalea.sch, begonia.kicad_pcb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]
2019-08-30 Added acrylic case svg file; updated README to include acrylic case
2019-10-09 Added licensing info to the README file in two places - under Azalea header, and under Acrylic Case header
2020-07-03 adopt OSHWA convention for SPI signal names https://www.oshwa.org/a-resolution-to-redefine-spi-signal-names
    [azalea.kicad_pcb, azalea.sch]
2021-11-24 GF1 Hardware: Update schematic for modern KiCAD
    [azalea.sch]
2021-11-24 GF1 Hardware: Rotate FB symbols to correct orientation.
    [azalea.sch]
2021-11-29 GF1 hardware: Update U5 & R23 with AP22653AW6-7 p/n and res value.
    [azalea.sch]
2021-11-29 GF1 hardware: Update PCB to reflect U5 & R23 peart changes.
    [azalea.kicad_pcb]
2021-12-03 GF1 hardware: Update references from MOSI/MISO or COPI/CIPO to PICO/POCI
    [azalea.kicad_pcb, azalea.sch]
2022-03-08 update date on silkscreen
    [azalea.kicad_pcb]

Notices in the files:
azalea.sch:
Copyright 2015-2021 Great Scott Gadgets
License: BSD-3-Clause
